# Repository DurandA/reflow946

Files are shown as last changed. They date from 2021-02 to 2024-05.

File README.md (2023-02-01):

# Reflow946

The Reflow946 is a Bluetooth LE temperature controller for the 946C electronic hot plate. Using this controller, a reflow profile can be programmed from your web browser using the [Web Bluetooth](https://webbluetoothcg.github.io/web-bluetooth/) API. You can use preset profiles (e.g. for lead-free or leaded soldering) or create a custom profile for a perfect cheese fondue. 🫕

UYUE-946C

The controller board is intended to replace the original controller board. It is **only compatible with the 3 buttons variant** pictured above (see this [teardown](https://youtu.be/Gv2sRJ9y_Ok)). Please send a PR if you adapted the design to a new variant.

## Hardware

The controller is based on a ESP32 module with an IPEX antenna. Since the metal case acts as a Faraday cage, the BLE signal can be improved by taping an antenna outside of the case.

### Front

PCB front

### Back

PCB back

## Status

- [x] Temperature control
  - [x] Temperature control using the front panel
  - [x] [BLE GATT service](https://github.com/DurandA/reflow946-firmware/wiki/GATT-Services) for temperature control
- [x] Reflow profile programming
  - [x] [BLE GATT service](https://github.com/DurandA/reflow946-firmware/wiki/GATT-Services) for reflow profiles
  - [x] [Web Bluetooth application](https://duranda.github.io/reflow946/)

## Credits

* Arnaud Durand - Orignal design
* Elías Rodríguez Martín - Revision 1.1, conversion to KiCad

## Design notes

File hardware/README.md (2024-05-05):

# Hardware

The Reflow946 hardware design is available on [https://easyeda.com/DurandA/reflow](https://easyeda.com/DurandA/reflow).

Contributions in converting the project to KiCad are welcome.

## Revision 1.0

### ESP32 module variants

⚠️ There are 85°C and 105°C variants of the ESP32-WROOM-32U(E) module. When heating stuff with a large termal mass, the temperature inside the case can largely exceed 85°C, causing glitches and reboots of the ESP32. It is advised to use the H version of the module.



### BOM

| Name | Designator | Footprint | Quantity | Supplier |
|---|---|---|---|---|
| MOC3041M | U1 | DIP-6_L8.5-W6.4-P2.54-LS7.6-BL | 1 | [LCSC](https://lcsc.com/product-detail/C8921.html) |
| ESP32-WROOM-32UE-H4 | U2 | WIFIM-SMD_39P-L19.2-W18.0-P1.27 | 1 | [LCSC](https://lcsc.com/product-detail/C3013922.html) |
| MAX31855KASA | U3 | SO-8_L4.9-W3.9-P1.27-LS5.9-BL | 1 | [LCSC](https://lcsc.com/product-detail/C52028.html) |
| AMS1117-3.3 | U4 | SOT-223-3_L6.5-W3.4-P2.30-LS7.0-BR | 1 | [LCSC](https://lcsc.com/product-detail/C6186.html) |
| ~EL817~ | U5 | SOP-4_L6.5-W4.6-P2.54-LS10.2-TL | ~1~ | ~[LCSC](lcsc.com/product-detail/C183799.html)~ |
| 100nF | CBB1 | CAP-TH_L13.0-W6.0-P10.00-D1.2 | 1 | [LCSC](https://lcsc.com/product-detail/C105712.html) |
| 1000uF/25V | C1 | CAP-D10.0×F5.0 | 1 |  |
| 10u | C2,C3 | C0805 | 2 |  |
| 0.01u | C4 | C0603 | 1 |  |
| 10u | C5 | C0603 | 1 |  |
| 0.1u | C6 | C0603 | 1 |  |
| MB6F | D1 | MBF_L4.8-W3.9-P2.50-LS6.7-BL | 1 | [LCSC](https://lcsc.com/product-detail/C2490.html) |
| SM4007PL | D2 | SOD-123F_L2.8-W1.8-LS3.7-RD | 1 | [LCSC](https://lcsc.com/product-detail/C64898.html) |
| HDR-M-2.54_2x3 | ESP-PROG | HDR-M-2.54_2X3 | 1 | [LCSC](https://lcsc.com/product-detail/C65114.html) |
| SMD0805-020-16V | F1 | F0805 | 1 | [LCSC](https://lcsc.com/product-detail/C70057.html) |
| ~CBG100505U260T~ | L1,L2 | L0402 | ~2~ | ~[LCSC](https://lcsc.com/product-detail/C668229.html)~ |
| 3bit common anode 0.4" LED segment display | LED1 | LED-SEG-TH_12P-L30.1-W16.0-P2.54-S12.70-BL | 1 | [LCSC](https://lcsc.com/product-detail/C105656.html) |
| VH-2A | P1 | CONN-TH_VH3.96-2A | 1 | [LCSC](https://lcsc.com/product-detail/C16728.html) |
| VH3.96-3P2 | P2,P3 | CONN-TH_VH3.96-3P2 | 2 | [LCSC](https://lcsc.com/product-detail/C18157.html) |
| XH-2A | P4 | CONN-TH_XH-2A | 1 | [LCSC](https://lcsc.com/product-detail/C20079.html) |
| BTA16-600BRG | Q1 | TO-220-3_L10.0-W4.5-P2.54-L | 1 | [LCSC](https://lcsc.com/product-detail/C9100.html) |
| MMBT3904 | Q2,Q3,Q4 | SOT-23-3_L2.9-W1.3-P1.90-LS2.4-BR | 3 | [LCSC](https://lcsc.com/product-detail/C20526.html) |
| 220 | R1,R10,R11,R12,R13,<br>R14,R15,R16,R17 | R0603 | 9 |  |
| ~1k~ | R2,R21 | R0603 | ~2~ |  |
| 30 | R3 | R_AXIAL-0.5 | 1 |  |
| 330 | R4 | R_AXIAL-0.5 | 1 |  |
| 100R/2W | R5 | R_AXIAL-0.6 | 1 |  |
| 10k | R6,R8 | R0603 | 2 |  |
| D6C40F1LFS | SW1,SW2,SW3 | | 3 | [LCSC](https://lcsc.com/product-detail/C2689630.html) |
| uFL antenna | | | 1 | [AliExpress](https://aliexpress.com/item/4000044880454.html) |

Ferrite beads (`L1`, `L2`) are not really required, you can make a solder bridge.

### Errata

- ⚠️ `U3` (_MAX31855KASA_) has [reverse polarity on K element](https://github.com/DurandA/reflow946/issues/7) and [`MISO` and `CLK` pins are swapped](https://github.com/DurandA/reflow946/issues/6) on revision 1.1.
- Zero-cross detection circuitry is not required with the use of the MOC3041 and will be removed in future revisions of the board. You do not need to populate `U5`, `R2`, `R21` and you can use a 0Ω resistor over `D2` footprint.

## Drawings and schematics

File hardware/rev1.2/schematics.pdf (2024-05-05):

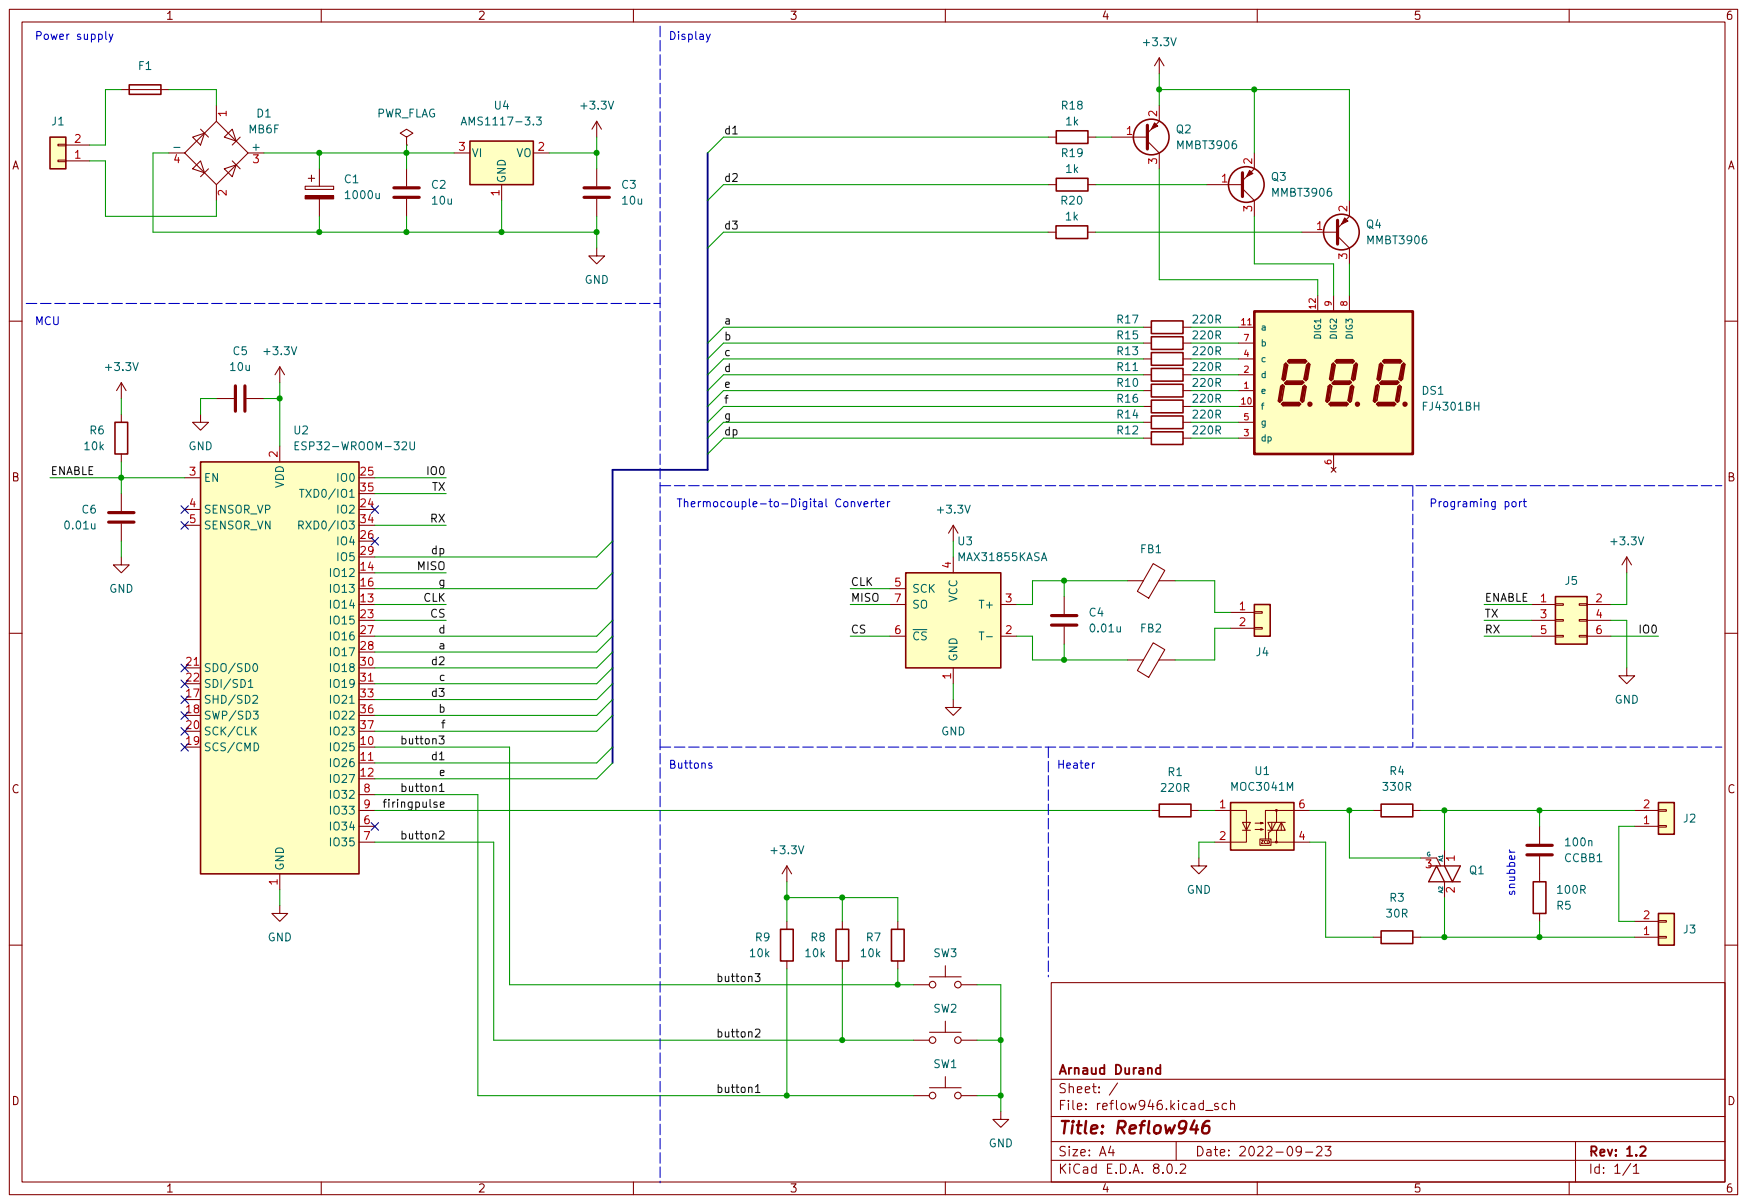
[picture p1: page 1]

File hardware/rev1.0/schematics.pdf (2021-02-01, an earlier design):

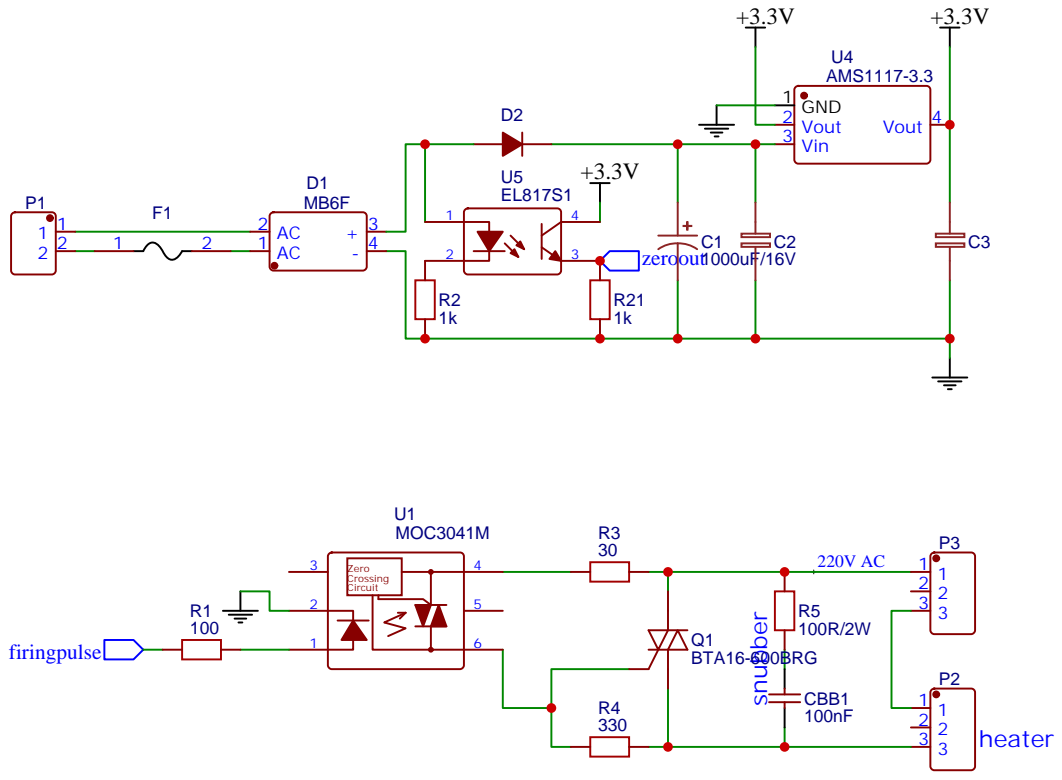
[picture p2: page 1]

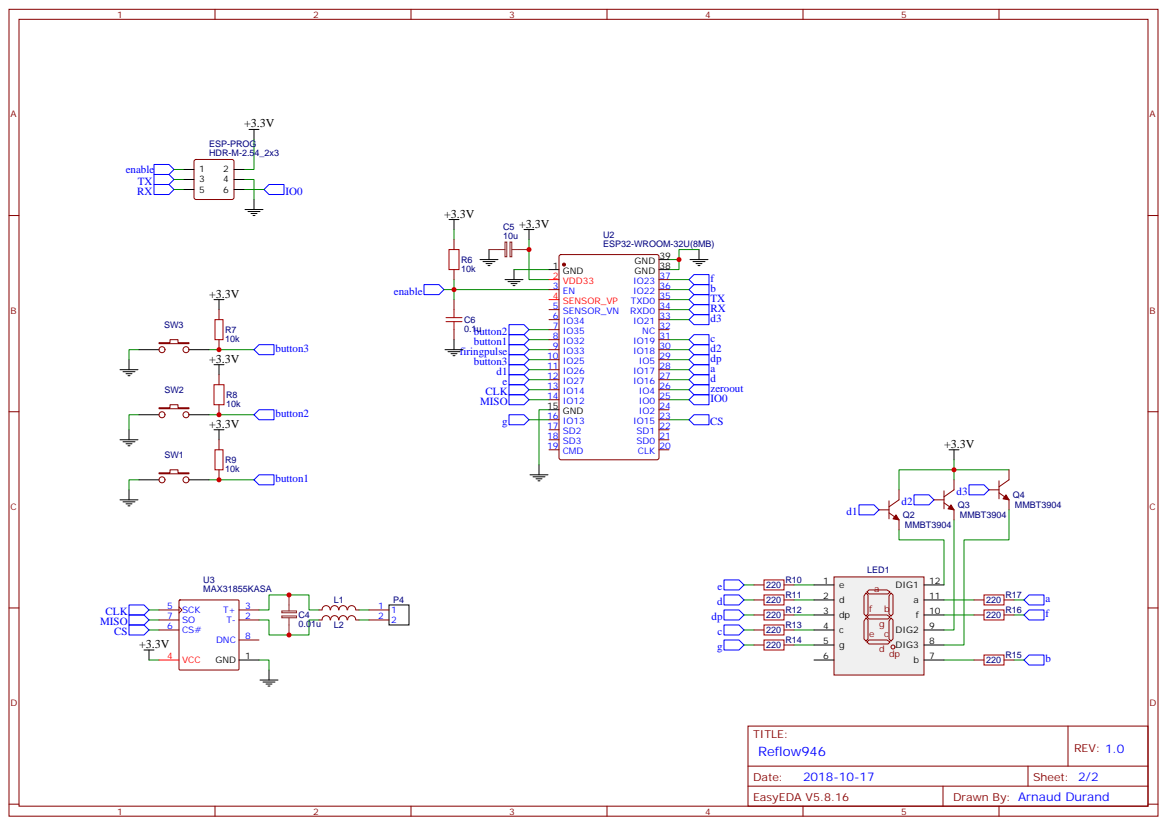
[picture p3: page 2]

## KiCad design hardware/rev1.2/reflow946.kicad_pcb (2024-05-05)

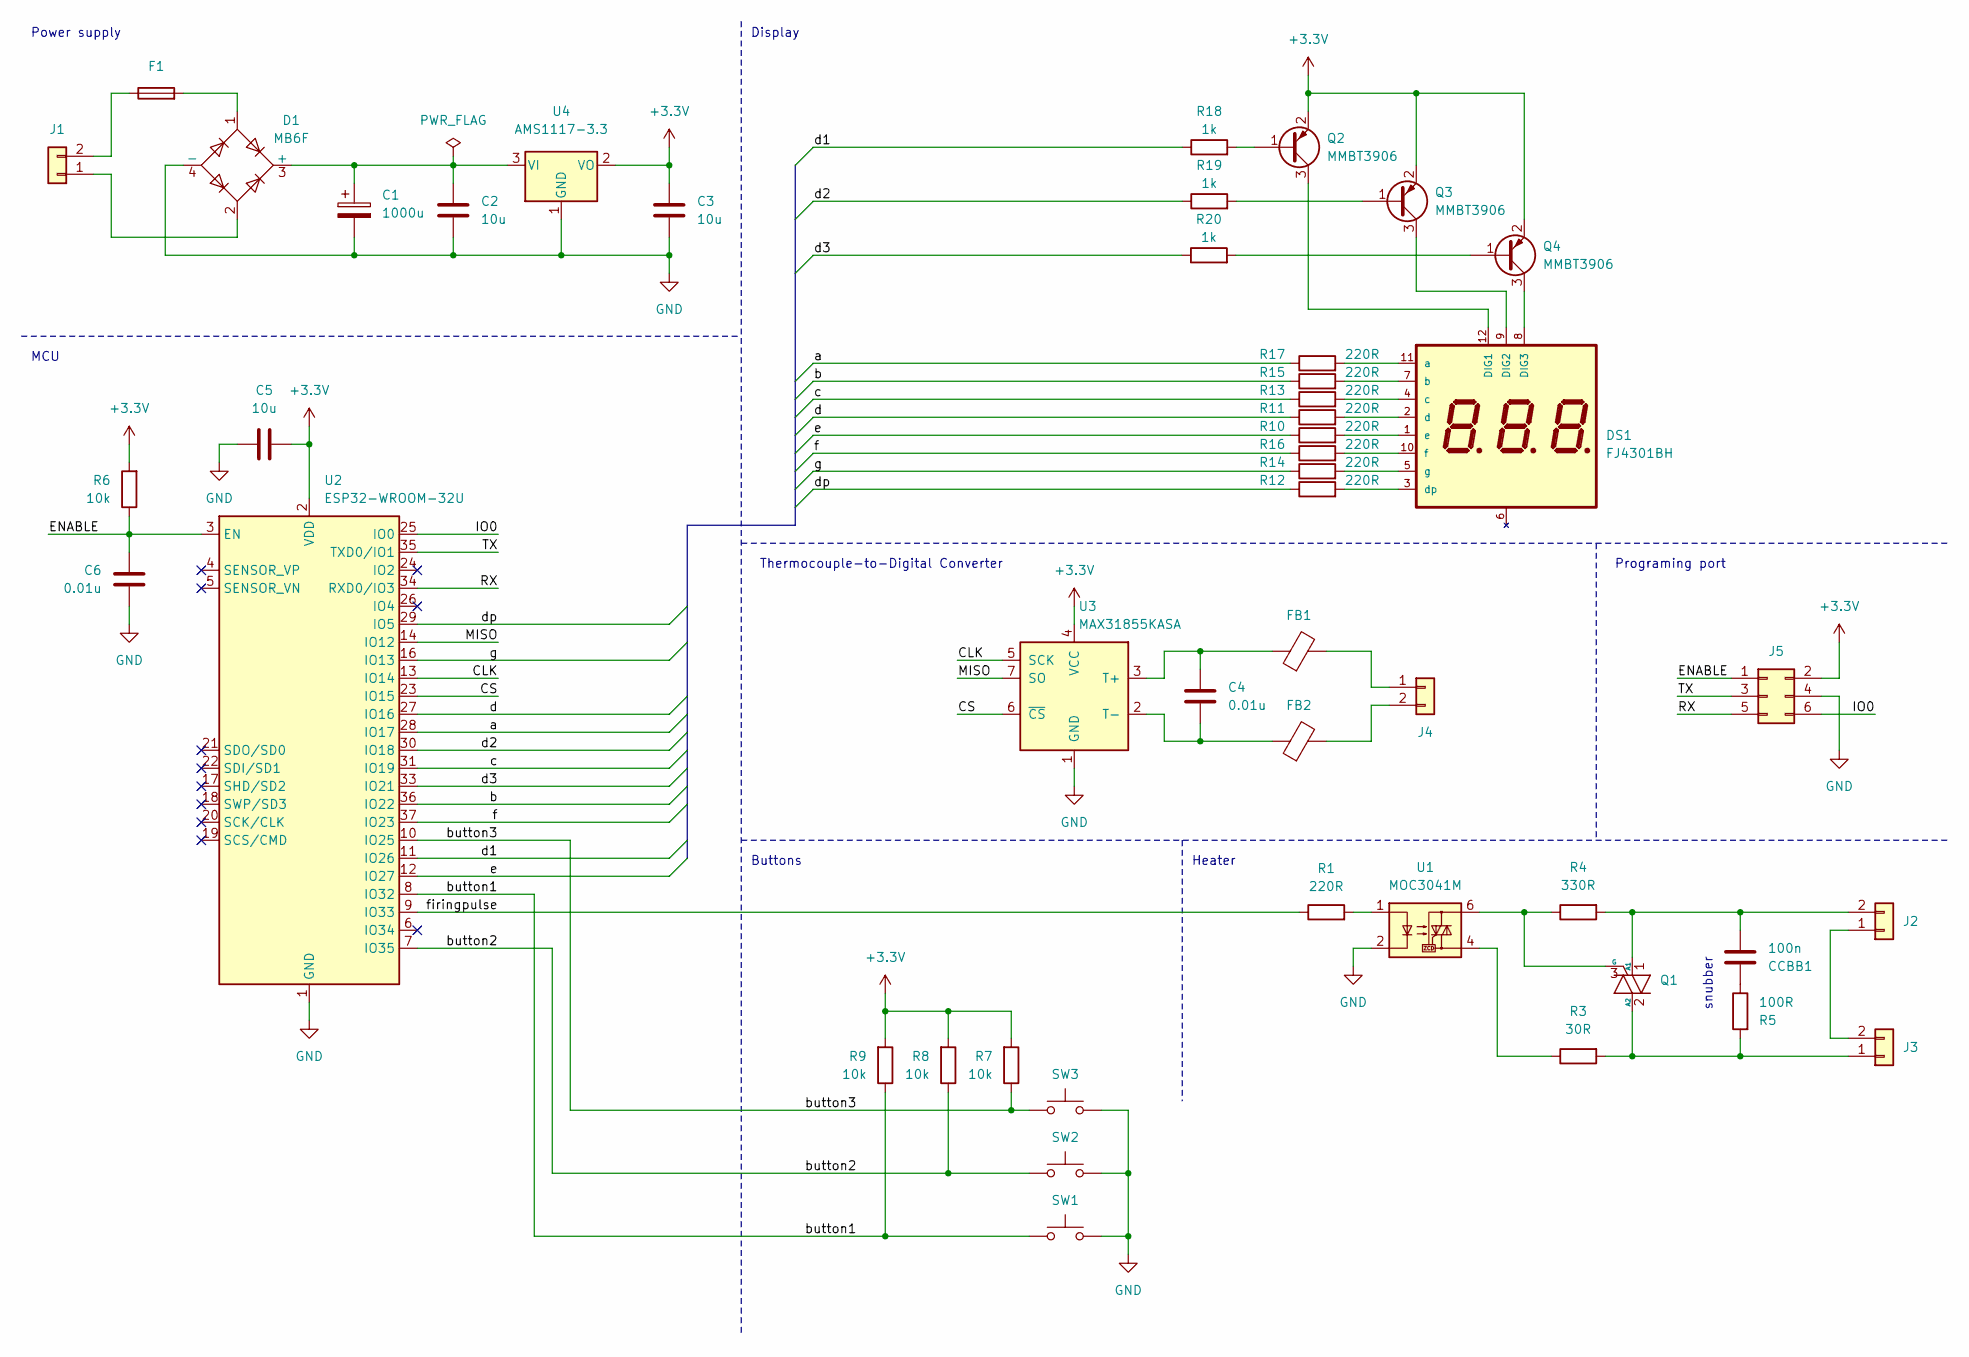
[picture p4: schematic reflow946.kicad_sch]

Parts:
C1: 1000u; CP_Radial_D10.0mm_P5.00mm
C2, C3, C5: 10u; C_0805_2012Metric_Pad1.18x1.45mm_HandSolder
C4, C6: 0.01u; C_0805_2012Metric_Pad1.18x1.45mm_HandSolder
CCBB1: 100n; C_Rect_L13.0mm_W6.0mm_P10.00mm_FKS3_FKP3_MKS4; Part Number MP1104K44C3R6LC; LCSC Part # C105712
D1: MB6F; MB-F; Part Number MB6F; LCSC Part # C2490
DS1: FJ4301BH; Part Number C10706; LCSC Part # C10706
F1: SMD0805-020-16V; Fuse_0805_2012Metric_Pad1.15x1.40mm_HandSolder; Part Number SMD0805-020-16V; LCSC Part # C70057
FB1, FB2: FerriteBead; R_0603_1608Metric_Pad0.98x0.95mm_HandSolder
J1: VH-2A; JST_VH_B2P-VH_1x02_P3.96mm_Vertical; Part Number VH-2A; LCSC Part # C16728
J2, J3: VH-3A2; JST_VH_B2P3-VH_1x02_P7.92mm_Vertical; Part Number VH-3A2; LCSC Part # C18157
J4: XH-A2; CONN-TH_XH-2A; Part Number XH-2A; LCSC Part # C20079
J5: HDR-M-2.54_2x3; PinHeader_2x03_P2.54mm_Vertical; Part Number C65114; LCSC Part # C65114
Q1: BTA16-600BRG; TO-220-3_Horizontal_TabUp; Part Number BTA16-600BRG; LCSC Part # C9100
Q2, Q3, Q4: MMBT3906; SOT-23; Part Number MMBT3906; LCSC Part # C181120
R1, R10, R11, R12, R13, R14, R15, R16, R17: 220R; R_0603_1608Metric_Pad0.98x0.95mm_HandSolder
R3: 30R; R_Axial_DIN0309_L9.0mm_D3.2mm_P12.70mm_Horizontal
R4: 330R; R_Axial_DIN0309_L9.0mm_D3.2mm_P12.70mm_Horizontal
R5: 100R; R_Axial_DIN0414_L11.9mm_D4.5mm_P15.24mm_Horizontal
R6, R7, R8, R9: 10k; R_0603_1608Metric_Pad0.98x0.95mm_HandSolder
R18, R19, R20: 1k; R_0603_1608Metric_Pad0.98x0.95mm_HandSolder
SW1, SW2, SW3: SW_Push; SW-TH_D6C10F1LFS; Part Number D6C40F1LFS; LCSC Part # C2689630
U1: MOC3041M; DIP-6_W7.62mm_LongPads; Part Number MOC3041M; LCSC Part # C8921
U2: ESP32-WROOM-32U; Part Number ESP32-WROOM-32U-H4; LCSC Part # C3013938
U3: MAX31855KASA; SOIC-8_3.9x4.9mm_P1.27mm; Part Number MAX31855KASA+T; LCSC Part # C52028
U4: AMS1117-3.3; SOT-223-3_TabPin2; Part Number AMS1117-3.3; LCSC Part # C6186

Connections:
+3.3V: C3.1, C5.2, J5.2, Q2.2 (E), Q3.2 (E), Q4.2 (E), R6.2, R7.2, R8.2, R9.2, U2.2 (VDD), U3.4 (VCC), U4.2 (VO)
/CLK: U2.13 (IO14), U3.5 (SCK)
/CS: U2.23 (IO15), U3.6 (~CS)
/ENABLE: C6.2, J5.1, R6.1, U2.3 (EN)
/IO0: J5.6, U2.25 (IO0)
/MISO: U2.14 (IO12), U3.7 (SO)
/RX: J5.5, U2.34 (RXD0/IO3)
/TX: J5.3, U2.35 (TXD0/IO1)
/a: R17.1, U2.28 (IO17)
/b: R15.1, U2.36 (IO22)
/button1: R9.1, SW1.1, U2.8 (IO32)
/button2: R8.1, SW2.1, U2.7 (IO35)
/button3: R7.1, SW3.1, U2.10 (IO25)
/c: R13.1, U2.31 (IO19)
/d: R11.1, U2.27 (IO16)
/d1: R18.1, U2.11 (IO26)
/d2: R19.1, U2.30 (IO18)
/d3: R20.1, U2.33 (IO21)
/dp: R12.1, U2.29 (IO5)
/e: R10.1, U2.12 (IO27)
/f: R16.1, U2.37 (IO23)
/firingpulse: R1.1, U2.9 (IO33)
/g: R14.1, U2.16 (IO13)
GND: C1.2, C2.2, C3.2, C5.1, C6.1, D1.4 (-), J5.4, SW1.2, SW2.2, SW3.2, U1.2, U2.1 (GND), U2.15 (GND), U2.38 (GND), U2.39 (GND), U3.1 (GND), U4.1 (GND)
unnamed: CCBB1.1, R5.1
unnamed: C1.1, C2.1, D1.3 (+), U4.3 (VI)
unnamed: D1.1, F1.2
unnamed: DS1.12 (DIG1), Q2.3 (C)
unnamed: DS1.9 (DIG2), Q3.3 (C)
unnamed: DS1.8 (DIG3), Q4.3 (C)
unnamed: DS1.11 (a), R17.2
unnamed: DS1.7 (b), R15.2
unnamed: DS1.4 (c), R13.2
unnamed: DS1.2 (d), R11.2
unnamed: DS1.3 (dp), R12.2
unnamed: DS1.1 (e), R10.2
unnamed: DS1.10 (f), R16.2
unnamed: DS1.5 (g), R14.2
unnamed: D1.2, J1.1
unnamed: F1.1, J1.2
unnamed: J2.1, J3.2
unnamed: CCBB1.2, J2.2, Q1.1 (A1), R4.2
unnamed: J3.1, Q1.2 (A2), R3.2, R5.2
unnamed: FB1.2, J4.1
unnamed: FB2.2, J4.2
unnamed: Q1.3 (G), R4.1, U1.6
unnamed: Q2.1 (B), R18.2
unnamed: Q3.1 (B), R19.2
unnamed: Q4.1 (B), R20.2
unnamed: R1.2, U1.1
unnamed: R3.1, U1.4
unnamed: C4.1, FB1.1, U3.3 (T+)
unnamed: C4.2, FB2.1, U3.2 (T-)

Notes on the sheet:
Power supply
Programing port
Thermocouple-to-Digital Converter
snubber
MCU
Heater
Display
Buttons

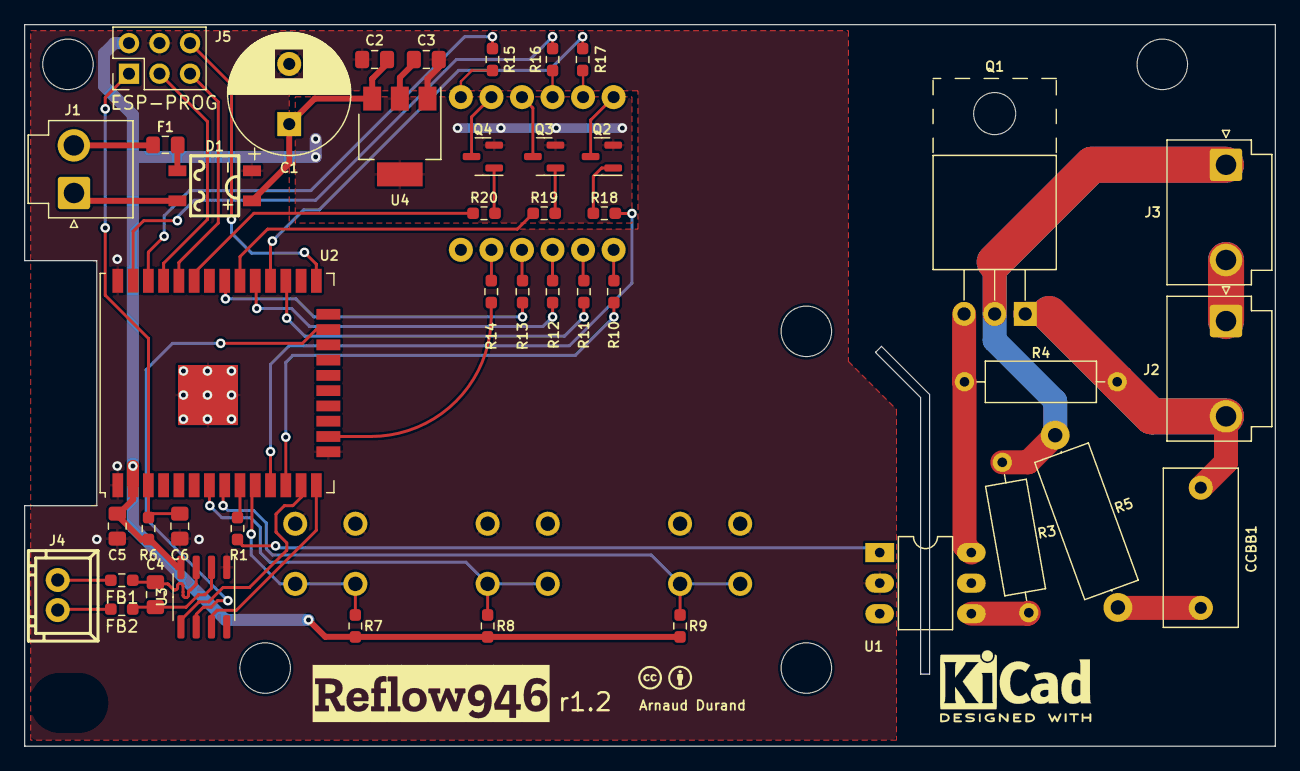
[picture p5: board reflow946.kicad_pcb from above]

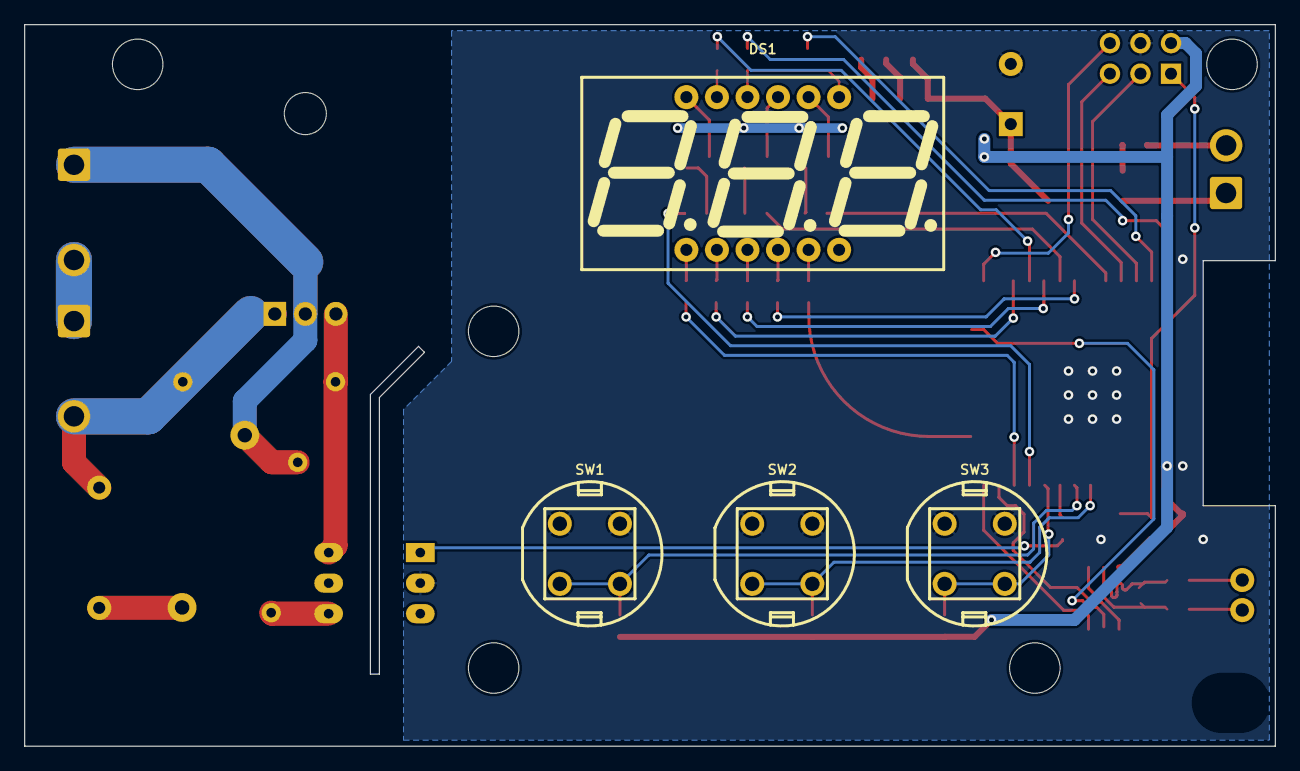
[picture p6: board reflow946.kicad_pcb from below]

Board: 2 copper layers, 104.0 x 60.0 mm, 48 parts (4 on the bottom side), 53 nets.

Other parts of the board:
kibuzzard-632CED8E: G***; kibuzzard-632CED8E

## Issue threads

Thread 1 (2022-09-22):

KiCad

Ortogonale, 2022-09-22:
Hi,  I can help with KiCad 5.x can you please share the physical dimension of the board with holes etc.. in CAD file format?

DurandA, 2022-09-22:
Hi @Ortogonale and thank you for proposing your help.

> in CAD file format

Are you thinking about one format in particular? Would a drawing be good enough?

@eliasrm87 from Twitter also told me that he his working on a Kicad design.

eliasrm87, 2022-09-22:
Hi @Ortogonale, I'm currently working on a KiCad 6.x project that I will be requesting to be merged soon.

Closed 2022-09-23.

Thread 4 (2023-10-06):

Support new variant

Toniob, 2023-10-06:
Hello,

I have received this new version of the 946C :
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

The PCB look really different :
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

Do you think we could adapt yours to make it work with this new version ?

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

Thanks

russkel, 2024-06-05:
Did you end up adapting the board? I have one of these on the way.

Toniob, 2024-06-05:
Sorry but I didn’t have the skills to do it yet.

russkel, 2024-06-10:
I had a look at the differences and there isn't many at all. Looks like we just need to change the connectors used on the board.

Do you mind measuring the distances between the centres of the displays and the three buttons? Need to see if the button locations need to be updated.

Toniob, 2024-06-12:
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

Good for you ?

russkel, 2024-06-12:
Perfect, thanks.

My hardware should be arriving soon.

russkel, 2024-06-15:
Okay so it is a bit more different. Looks like the older model has the transformer mounted separately where this version has it on the PCB and the AC power is routed through the board. ~800W through a PCB trace seems like a lot...

russkel, 2024-06-15:
The transformer is now part of the PCB, so the power supply for the DC side is not going to work. I might replace it with a AC to DC module and be done with it.

russkel, 2024-06-16:
I have been hacking at it.

* Replaced the buttons with the same ones
* Removed voltage rectifier circuitry as the 9VAC is no longer present.
* Added a 230VAC to 3.3V DC module
* Removed AC connectors and replaced with screw terminals

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

I am hoping @DurandA is willing to give this a look over at some point as I really haven't much experience with AC PCB design.

I was wondering if I should use a 230VAC to 12V DC instead and then add a fan controller..

DurandA, 2024-06-17:
Hi @russkel. Thank you for sharing your work, it is very nice to see other people playing with the design.

What power supply module are you using? Some Hi-Link HLK-*? I saw there are some really compact ones. I also saw that the datasheet recommends a MOV and an inductor at the input.

> I am hoping @DurandA is willing to give this a look over at some point as I really haven't much experience with AC PCB design.

I am by no means an expert in AC design as this is my only AC board ever. :laughing: I just followed some rules of thumb and recreated the spark gap present in the original board. Looking at your design on the AC side, I would increase trace width to improve thermal dissipation and keep traces as distant as possible from each other.

It would be nice to have a feedback from a real expert to be on the safe side.

> I was wondering if I should use a 230VAC to 12V DC instead and then add a fan controller.

Is it to cool the heater surface or the controller board? Normally passive cooling should be OK if you use a [105°C ESP32 variant](https://github.com/DurandA/reflow946/tree/master/hardware#esp32-module-variants). I use a 85°C variant without cooling, and I once experienced some constant reboots while heating a large thermal mass (a cheese fondue).

russkel, 2024-06-17:
> Hi @russkel. Thank you for sharing your work, it is very nice to see other people playing with the design.

Hi @DurandA, my pleasure. Thanks for sharing it in the first place.

> What power supply module are you using? Some Hi-Link HLK-*? I saw there are some really compact ones. I also saw that the datasheet recommends a MOV and an inductor at the input.

Yes, it's a HLK-5M03. If you find a better option please let me know. It looks big, but that might be because the board itself isn't that big. I am aware of the those two components, but I wasn't sure how necessary they are. The datasheet mentions it is for certification, not sure what that means exactly. I will have to rejig things a bit to fit them in.

> Looking at your design on the AC side, I would increase trace width to improve thermal dissipation and keep traces as distant as possible from each other.

I will try and increase them, but I am getting quite limited in space, and the routing is a bit difficult as both sides are used. I will post some better drawings soon (and push my branch) after I get the heater hardware in my hand and can measure and determine what board holes are required and where.

> Is it to cool the heater surface or the controller board? Normally passive cooling should be OK if you use a [105°C ESP32 variant](https://github.com/DurandA/reflow946/tree/master/hardware#esp32-module-variants). I use a 85°C variant without cooling, and I once experienced some constant reboots while heating a large thermal mass (a cheese fondue).

It would be to cool the heater surface somehow. I haven't checked where I could mount a slim fan yet. I would also add an additional header for a board fan. I did see your comment on the high temp variant and it got me a little bit concerned, the temp-performance curve of the AC-DC converter also is a bit concerning. These parts could be left unpopulated if a fan is not desired, so seemed like an okay idea. The only 'issue' would be the 12V rail for fans. I would have to use a 230VAC to 12V converter instead of a 230VAC to 3.3V, and then add a regulator for the 3.3V rail.

I actually though the fondue was a joke :laughing:, but why not :cheese:.

The final thing I wanted to do was replace the LCD segment display with one of these https://www.lcsc.com/product-detail/Organic-Light-Emitting-Diode-Display-Screen_HS-HS13L03W2C01_C7465997.html. Similar to what this guy did:
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
(https://www.e-tinkers.com/2021/07/converting-uyue-preheater-into-a-solder-reflow-hot-plate/) Should I make that in a separate revision as it does remove quite a lot of the original design. The removal of these parts and replacing with modules does simplify the BOM quite considerably which I think is desirable for hobbyist one offs (although maybe it is moot given it's for people making PCB, who probably have most of the BOM parts already).

Toniob, 2024-06-17:
Great work ! Thank you.

When I checked what was possible, I’ve found those fans : https://fr.aliexpress.com/item/1005005736257626.html . I bought one and it’s working great (it’s 5V and PWM, and has a good flow). Maybe you can use a 230 to 5V module, and an AMS1117 or something like that to have your 3.3V ?

russkel, 2024-06-17:
> Great work ! Thank you.
>
> When I checked what was possible, I’ve found those fans : https://fr.aliexpress.com/item/1005005736257626.html . I bought one and it’s working great (it’s 5V and PWM, and has a good flow). Maybe you can use a 230 to 5V module, and an AMS1117 or something like that to have your 3.3V ?

I think 12V fans are more common and therefore are cheaper and have more selection especially from Aliexpress. I found a slim fan that was 25mm tall and it was pretty cheap. Something of similar size to what you linked to would be good for a board fan.

Pegoku, 2024-10-26:
Hi, how it this new version going? I'd like to buy one of the new model, and want to know if I'll be able to use this mod. Thanks

russkel, 2024-10-27:
> Hi, how it this new version going? I'd like to buy one of the new model, and want to know if I'll be able to use this mod. Thanks

Hi,

It's getting close, but none of the firmware is written nor hardware assembled/tested. I wouldn't expect plug and play any time soon.

DaniGarciaLopez, 2025-03-02:
Any updates? I'm also looking forward for the new design

russkel, 2025-03-02:
Life has gotten in the way. I need more people bugging (😉 ) me like this so I finish it. I have put in a smaller (cheaper) ESP32 module. I am trying to replace the SPI thermocouple IC with something cheaper and I2C.

I will upload some more pictures and schematics.

DaniGarciaLopez, 2025-03-03:
I'm also pretty short on time lately, but I might be able to test it out and help a bit. I'll be getting mine in a few weeks, so I haven't had a chance to tinker with it yet. I also think adding a small 1.3" display would be a great addition!

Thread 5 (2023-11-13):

HW 1.1 wrong segment display referenced in BOM and schematics

Quas7, 2023-11-13:
Hi,

first of all to the devs: thanks for sharing the design!

I am currently debugging my build and besides reading temperature 0°C (SPI issue?) I think the segment display is wrongly referenced as a FJ4301BH
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

but it should be an FJ4301F or similar to make use of Q2-Q4 common anode configuration:
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

My FJ4301BH is currently just overlaying the digits but can show clean "0 0 0" ;)

Quas7, 2023-11-16:
After exchanging the segment display with a LTD040BUE-101A I still do not get proper characters displayed.

I checked the correct pinout of GPIO_OUTPUT_SEGMENTS and it does not seem to be a hardware issue. So, at that point I was close to replacing the segment LED with an OLED display. ;)

As I understand the code, the segments get scanned (updated) every few milliseconds based on a GPTimer.
But looking at my Oszi on the cathode pins I see most of the time a PWM signal with 1:2 or 2:1 millisec high:low and that keeps the "off" segments still around 80% of their full brightness.

By shifting GPTimer functions and ISR into IRAM via the sdkconfig this issue is now fixed.

Adding to sdkconfig.defaults these lines should do the trick:
```
CONFIG_GPTIMER_CTRL_FUNC_IN_IRAM=y
CONFIG_GPTIMER_ISR_IRAM_SAFE=y
```

DurandA, 2024-04-10:
Hi @Quas7, thank you very much for the tip.

I will update the sdkconfig.defaults accordingly. Do you confirm that the correct reference is `FJ4301F`? There are tons of segment displays with similar size/pinout with different references.

I am also looking to update the design to an ESP32-C3/C6 and use a dedicated segment controller. It will slightly increase the BOM but the ESP32-C3 flash has a wider temperature tolerance (unless you take the high temperature version which is not alway available). I noticed some issues/reboots with the 85°C version when you try to heat something with a large mass such as a cheese fondue.

Quas7, 2024-04-10:
Hi @DurandA,

I think, the FJ4301F should work exactly as the LTD040BUE-101A does that I used as drop-in replacement.
Maybe you can take both into the BOM and mark the LTD as an alternative?

LTD040BUE-101A (confirmed as working, see [datasheet])(https://www.tme.com/Document/f09cee5f8a4f402791412558d418162c/LTD040BUE-101A.pdf))
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

FJ4301F (see [datasheet](https://datasheet.lcsc.com/lcsc/2001071432_Shenzhen-Zhihao-Elec-FJ4301BH-_C10706.pdf))
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

DurandA, 2024-05-04:
Fixed in bcea8101d5b6173054b414c2065849a1132cd23a for BOM.

DurandA, 2024-05-05:
Fixed in 11e58e171e20f5fd29d601baf653828abd1b1b3d to force GPTimer function to run in IRAM. Surprisingly, I did not encounter this issue. Maybe the default was changed after ESP-IDF 5.1.

Thank you very much @Quas7 for raising this.

Closed 2024-05-05.

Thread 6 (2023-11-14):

BUG: SPI MISO and CLK pins interchanged

Quas7, 2023-11-14:
MISO and CLK have been interchanged - no SPI connection to the MAX31855K this way.

[#define PIN_NUM_MISO 12](https://github.com/DurandA/reflow946-firmware/blob/6782341b24b91ee0388d14db7c9579f278806f31/main/max31855.c#L8)

Correct defines are:

```
#define PIN_NUM_MISO 14
#define PIN_NUM_CLK  12
```

DurandA, 2024-05-04:
Hi @Quas7 👋 and thanks for the feedback.

This is a mistake that was introduced with the Kicad version (rev 1.1), see #7 for more details. I will make a new revision.

DurandA, 2024-05-05:
Fixed in 5f84cfc61181377c1e6a4e7759f00b89bdffa89a. Thank you very much for raising this issue.

Closed 2024-05-05.

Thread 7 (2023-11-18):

BUG: K-Element pins swapped

Quas7, 2023-11-18:
I had to swap + ans - at my K element connector to get correct polarity. No big deal but rotating the connector socket would fix this.

DurandA, 2024-05-04:
Hi @Quas7 👋 and thanks for the feedback.

On my unit the connector has the right polarity. Can you post a picture of your original control board?

DurandA, 2024-05-04:
This is a mistake that was introduced with the Kicad version (rev 1.1):
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

On rev 1.0 the MAX31855K is connected differently:
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

Since I am still using the rev 1.0 and never assembled a rev 1.1, this went unnoticed. I will collect other issues and make a new revision.

DurandA, 2024-05-05:
Fixed in 5f84cfc61181377c1e6a4e7759f00b89bdffa89a. Thank you very much for raising this issue.

Closed 2024-05-05.

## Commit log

2022-09-18 Add gerber files of rev1.0
    [Drill_NPTH_Through.DRL, Drill_PTH_Through.DRL, Gerber_BoardOutlineLayer.GKO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]
2022-09-19 Update BOM
2022-09-24 Migrate project to KiCad v6.x
    First attempt at migrating the project from easyeda to KiCad v6.x.
    This version should be fully compatible with current firmware, execpt
    for DS1 annode driving, that should be inverted if MMBT3906 is used in
    place of MMBT3904.
    Note: Not including 3D models from firth parties, as they might have
    incompatible licences.
    [reflow946.kicad_pcb, reflow946.kicad_sch]
2022-09-24 Fix PNP transistors missplacement
    [reflow946.kicad_pcb, reflow946.kicad_sch]
2022-09-25 Assign standard 3D model to MB6F
    [reflow946.kicad_pcb]
2022-09-25 Use 0603 ferrite beads
    [reflow946.kicad_pcb, reflow946.kicad_sch]
2022-09-25 Move kicad folder to rev1.1
    [reflow946.kicad_pcb, reflow946.kicad_sch]
2024-05-04 Warn about ESP32 module version
2024-05-05 Upgrade project to KiCad 8.0
    [reflow946.kicad_pcb, reflow946.kicad_sch]
2024-05-05 Swap MAX31855 pins
    [reflow946.kicad_pcb, reflow946.kicad_sch]
